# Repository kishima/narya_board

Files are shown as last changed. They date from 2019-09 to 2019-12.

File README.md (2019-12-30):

# Narya board

Narya board is dedicated to [Family mruby](https://github.com/kishima/family_mruby) system.

Latest release is v2.0 and ESP32_WROVER_B_Breakout v1.0.

---

## Narya board v2.0

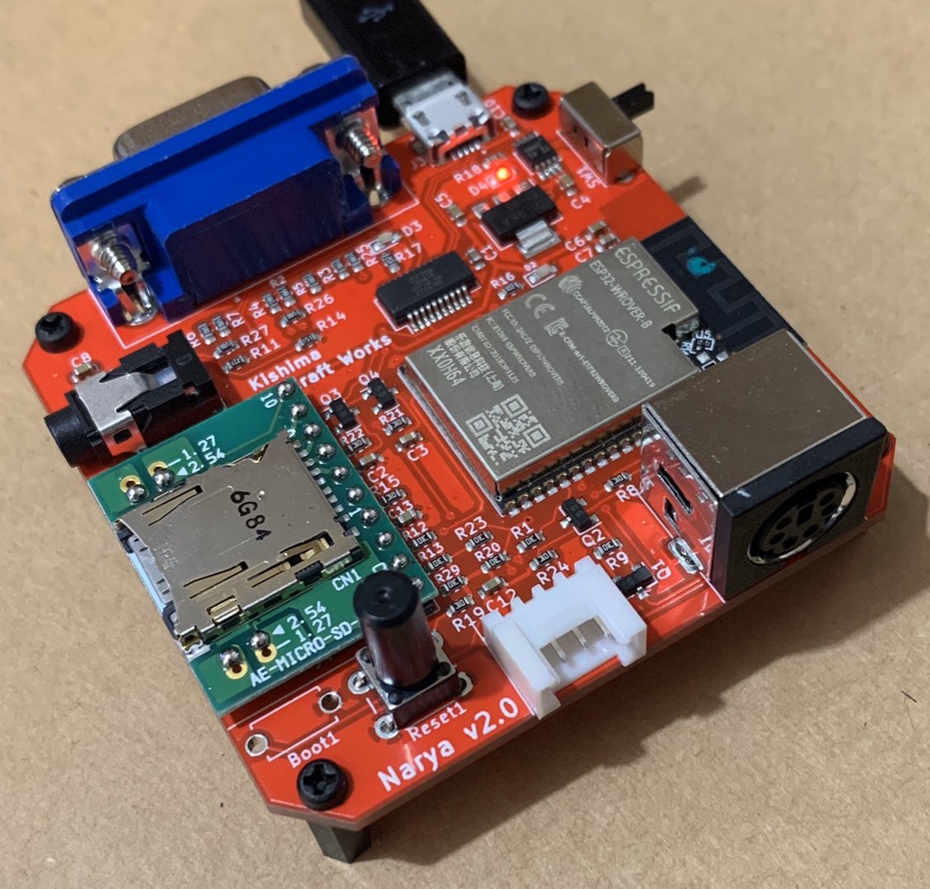
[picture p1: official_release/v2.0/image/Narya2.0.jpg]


CAD data of the case is also released.

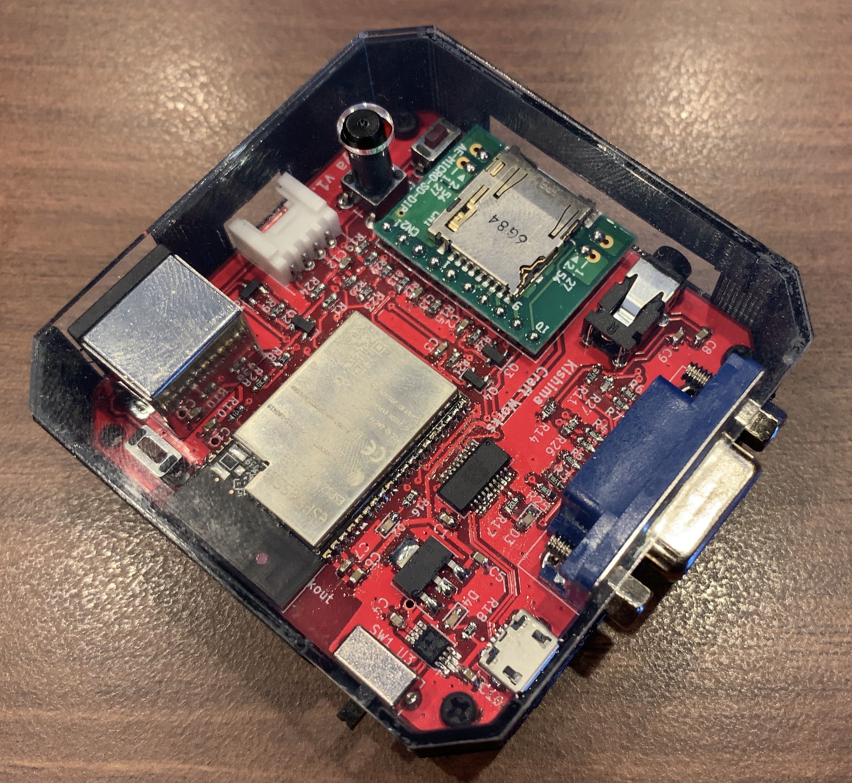
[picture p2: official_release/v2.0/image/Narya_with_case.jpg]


---

## Narya board v1.2

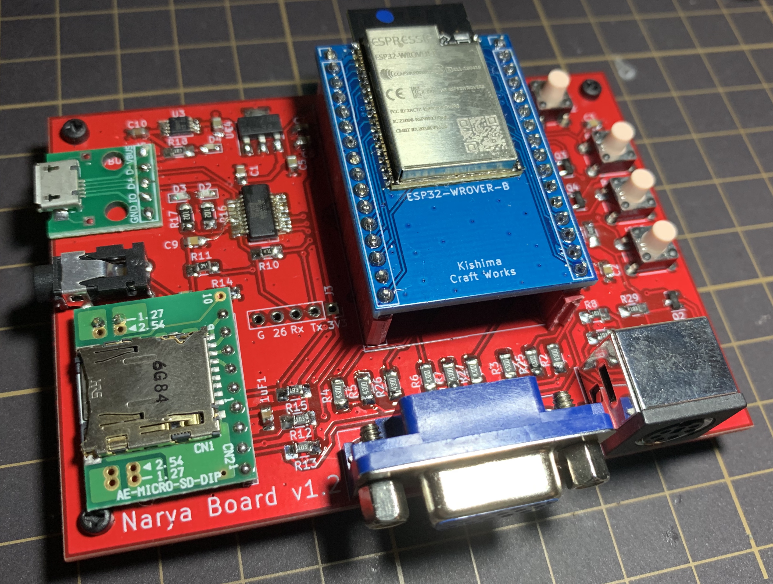
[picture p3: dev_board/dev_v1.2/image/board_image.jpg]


### Known issue

#### Artwork error

The pin16 of "US FT231XS" (GND) is floating in development board v1.2.

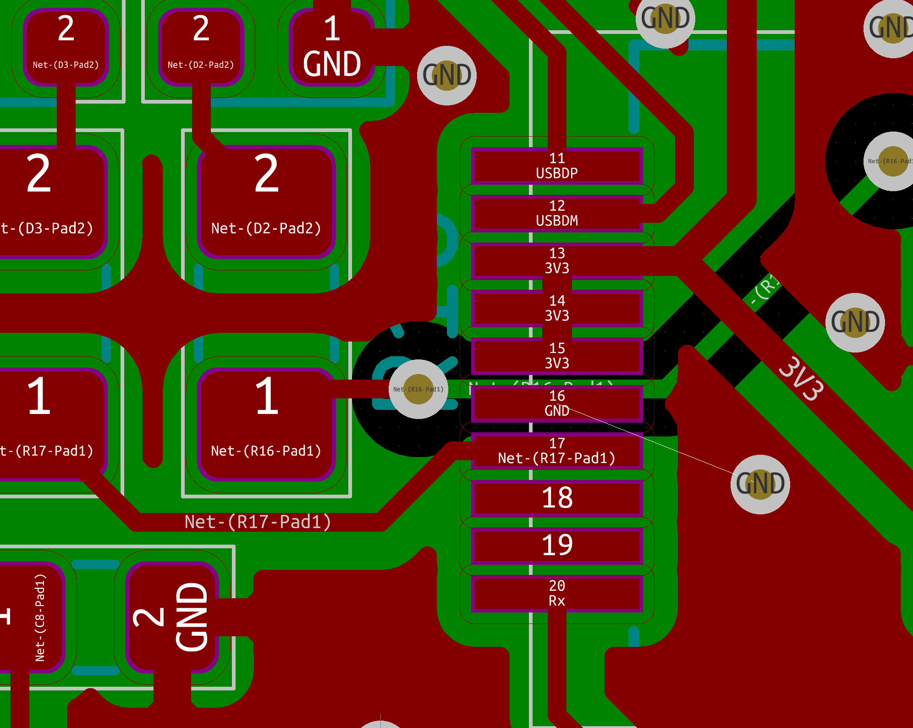
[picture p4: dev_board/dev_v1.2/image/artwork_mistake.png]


---

## History

### v2.0

First version of PCBA production. Released in C97.

Updates

* Fix problem about LED indication.
* Change the power source of the red LED.

### v1.4

Updates

* Update artwork for production.
* Add a GROVE connector
* Add a power swtich

### v1.3

Updates

* Fix issue about FT231X GND.

### v1.2

Released in Tech book fest 7.

### v1.0

First prototype.

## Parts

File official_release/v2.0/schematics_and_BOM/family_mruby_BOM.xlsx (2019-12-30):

# | Reference | Number | Value | Package | Manufacturer Part number | Description | Reference
1 | J6 | 1 | AudioJack2_Ground | myparts:Jack ST-005-G |  | AudioJack2_Ground | http://akizukidenshi.com/catalog/g/gC-02460/
2 | J1 | 1 | Conn_01x04_Male | myparts:GROVE_Connector |  | Conn_01x04_Male | http://akizukidenshi.com/catalog/g/gC-12634/
3 | J2 | 1 | Dsub15_Female | Connector_Dsub:DSUB-15 |  | DB15_Female_HighDensity | https://ja.aliexpress.com/item/32878535872.html?spm=a2g0s.9042311.0.0.7b6c4c4dq2qivm
4 | J4 | 1 | Micro_SD_Card | myparts:AKI-SD-slot |  | Micro_SD_Card | http://akizukidenshi.com/catalog/g/gK-05488/
5 | PS2 | 1 | Mini-DIN-6 | myparts:mini_DIN_6p_useconn |  | Mini-DIN-6 | http://akizukidenshi.com/catalog/g/gC-09385/
6 | C10, C1, C7 | 3 | 0.1uF | Capacitor_SMD:C_0603_1608Metric | CC0603KPX7R7BB104 | C | https://www.digikey.jp/product-detail/ja/yageo/CC0603KPX7R7BB104/311-1335-1-ND/2103119
7 | C3, C9, C2 | 3 | 10nF | Capacitor_SMD:C_0603_1608Metric | CC0603KPX7R9BB103 | C | https://www.digikey.jp/product-detail/ja/CC0603KPX7R9BB103/311-1572-1-ND/4340579/?itemSeq=310468665
8 | C8, C5, C4 | 3 | 10uF | Capacitor_SMD:C_0603_1608Metric | GRM188R61A106KE69J | C | https://www.digikey.jp/product-detail/ja/GRM188R61A106KE69J/490-14372-1-ND/6606833/?itemSeq=310469032
9 | C12, C11, C13 | 3 | 1uF | Capacitor_SMD:C_0603_1608Metric | CC0603KRX5R8BB105 | C | https://www.digikey.jp/product-detail/ja/yageo/CC0603KRX5R8BB105/311-1445-1-ND/2833751
10 | C6 | 1 | 22uF | Capacitor_SMD:C_0603_1608Metric | GRM188R61A226ME15D | C | https://www.digikey.jp/product-detail/ja/murata-electronics/GRM188R61A226ME15D/490-10476-1-ND/5026394
11 | D4 | 1 | LED-R | LED_SMD:LED_0603_1608Metric_Pad1.05x0.95mm_HandSolder | SML-D12U1WT86 | LED | https://www.digikey.jp/product-detail/ja/rohm-semiconductor/SML-D12U1WT86/SML-D12U1WT86CT-ND/5843858
12 | D2, D3 | 2 | LED-G | LED_SMD:LED_0603_1608Metric_Pad1.05x0.95mm_HandSolder | SML-D12M8WT86 | LED | https://www.digikey.jp/product-detail/ja/rohm-semiconductor/SML-D12M8WT86/511-1578-1-ND/1641810
13 | R14 | 1 | 150 Ohm | Resistor_SMD:R_0603_1608Metric | RC0603JR-07150RL | R | https://www.digikey.jp/product-detail/ja/RC0603JR-07150RL/311-150GRCT-ND/729661/?itemSeq=310471572
14 | R23, R15, R18, R1, R24, R19, R13, R29, R28, R8, R9, R20, R12, R21, R22 | 15 | 10K Ohm | Resistor_SMD:R_0603_1608Metric | RC0603FR-0710KL | R | https://www.digikey.jp/product-detail/ja/yageo/RC0603FR-0710KL/311-10.0KHRCT-ND/729827
15 | R17, R16 | 2 | 1K Ohm | Resistor_SMD:R_0603_1608Metric | RC0603JR-071KL | R | https://www.digikey.jp/product-detail/ja/yageo/RC0603JR-071KL/311-1.0KGRCT-ND/729624
16 | R11 | 1 | 270 Ohm | Resistor_SMD:R_0603_1608Metric | RC0603FR-07270RL | R | https://www.digikey.jp/product-detail/ja/yageo/RC0603FR-07270RL/311-270HRCT-ND/730050
17 | R6, R3, R2, R7, R5, R26, R4, R27, R25 | 9 | 402 Ohm | Resistor_SMD:R_0603_1608Metric | RC0603FR-07402RL | R | https://www.digikey.jp/product-detail/ja/yageo/RC0603FR-07402RL/311-402HRCT-ND/730169
18 | R10 | 1 | 470 Ohm | Resistor_SMD:R_0603_1608Metric | RC0603FR-07470RL | R | https://www.digikey.jp/product-detail/ja/yageo/RC0603FR-07470RL/311-470HRCT-ND/730203
19 | U1 | 1 | FT231XS | Package_SO:SSOP-20_3.9x8.7mm_P0.635mm | FT231XS-R | FT231XS | https://www.digikey.jp/product-detail/ja/ftdi-future-technology-devices-international-ltd/FT231XS-R/768-1129-1-ND/3029151
20 | U4 | 1 | AP7361C-33E | Package_TO_SOT_SMD:SOT-223-3_TabPin2 | AP7361C-33E-13 | AP7361C-33E | https://www.digikey.jp/product-detail/ja/AP7361C-33E-13/AP7361C-33E-13DICT-ND/5638331/?itemSeq=310400924
21 | Reset1 | 1 | SW_Push | Button_Switch_THT:SW_PUSH_6mm |  | SW_Push | http://akizukidenshi.com/catalog/g/gP-09824/
22 | IO35, Boot1 | 2 | SW_Push | myparts:TVBP06-BN043CR-B |  | SW_Push | http://akizukidenshi.com/catalog/g/gP-08213/
23 | SW1 | 1 | SW_Push_SPDT | myparts:SK-12D01-VG4 |  | SW_Push_SPDT | http://akizukidenshi.com/catalog/g/gP-08789/
24 | Q1, Q2, Q4, Q3 | 4 | BSS138 | Package_TO_SOT_SMD:SOT-23 | BSS138 | BSS138 | https://www.digikey.jp/product-detail/ja/BSS138/BSS138CT-ND/244294/?itemSeq=310461796
25 | J3 | 1 | 10118194-0001LF | 10118194-0001LF | 10118194-0001LF | 10118194-0001LF | https://www.digikey.jp/product-detail/ja/10118194-0001LF/609-4618-1-ND/2785382/?itemSeq=310466331
26 | UB1 | 1 | ESP32-WROVER-B | ESP32-WROVER-B_(16MB) | ESP32-WROVER-B (M213DH6464PC3Q0) | ESP32-WROVER-B | https://www.digikey.jp/product-detail/ja/ESP32-WROVER-B+(M213DH6464PC3Q0)/1904-1034-1-ND/9857845/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
19 | U3 | 1 | TPS2065DGNR | MSOP-8_3x3mm_P0.65mm | TPS2065DGNR | TPS2065 | https://www.digikey.jp/product-detail/ja/TPS2065DGNR/296-17314-1-ND/684819/?itemSeq=310404582

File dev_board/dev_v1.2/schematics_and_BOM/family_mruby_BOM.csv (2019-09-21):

Library | Part | Footprint | Value | Number | Reference | 調達先（例）
Connector | AudioJack2_Ground | myparts:Jack ST-005-G | AudioJack2_Ground | 1 | J6 | http://akizukidenshi.com/catalog/g/gC-02460/
Connector | Conn_01x05_Female | Connector_PinHeader_2.54mm:PinHeader_1x05_P2.54mm_Vertical | MicroUSB_DIP | 1 | J5 | https://www.amazon.co.jp/dp/B0183KF7TM/ref=cm_sw_em_r_mt_dp_U_rBJHDbKRYNB0A
Connector | Conn_01x05_Female | Connector_PinSocket_2.54mm:PinSocket_1x05_P2.54mm_Vertical | Pin_UARAT_IO26 | 1 | J3 | -
Connector | DB15_Female_HighDensity | Connector_Dsub:DSUB-15-HD_Female_Horizontal_P2.29x1.98mm_EdgePinOffset3.03mm_Housed_MountingHolesOffset4.94mm | Dsub15_Female | 1 | J2 | https://ja.aliexpress.com/item/32878535872.html?spm=a2g0s.9042311.0.0.4e0d4c4dXb4pk2
Connector | Micro_SD_Card | Connector_PinHeader_2.54mm:PinHeader_1x09_P2.54mm_Vertical | Micro_SD_Card | 1 | J4 | http://akizukidenshi.com/catalog/g/gK-05488/
Connector | Mini-DIN-6 | myparts:mini_DIN_6p_useconn | Mini-DIN-6 | 1 | PS2 | http://akizukidenshi.com/catalog/g/gC-09385/
Device | C | Capacitor_SMD:C_0805_2012Metric_Pad1.15x1.40mm_HandSolder | 0.1uF | 2 | C7, C1 | 千石電商等で
Device | C | Capacitor_SMD:C_0805_2012Metric_Pad1.15x1.40mm_HandSolder | 100nF | 1 | C10 | 千石電商等で
Device | C | Capacitor_SMD:C_0805_2012Metric_Pad1.15x1.40mm_HandSolder | 10nF | 3 | C2, C3, C9 | 千石電商等で
Device | C | Capacitor_SMD:C_0805_2012Metric_Pad1.15x1.40mm_HandSolder | 10uF | 3 | C8, C5, C4 | 千石電商等で
Device | C | Capacitor_SMD:C_0805_2012Metric_Pad1.15x1.40mm_HandSolder | 1uF | 1 | 1uF1 | 千石電商等で
Device | C | Capacitor_SMD:C_0805_2012Metric_Pad1.15x1.40mm_HandSolder | 22uF | 1 | C6 | 千石電商等で
Device | LED | LED_SMD:LED_0603_1608Metric_Pad1.05x0.95mm_HandSolder | LED | 3 | D2, D3, D4 | http://akizukidenshi.com/catalog/g/gI-03978/
Device | R | Resistor_SMD:R_1206_3216Metric_Pad1.42x1.75mm_HandSolder | 100 | 1 | R14 | 千石電商等で
Device | R | Resistor_SMD:R_1206_3216Metric_Pad1.42x1.75mm_HandSolder | 10K | 15 | R29, R22, R20, R13, R15, R18, R12, R23, R24, R28, R8, R21, R1, R19, R9 | 千石電商等で
Device | R | Resistor_SMD:R_1206_3216Metric_Pad1.42x1.75mm_HandSolder | 1K | 2 | R17, R16 | 千石電商等で
Device | R | Resistor_SMD:R_1206_3216Metric_Pad1.42x1.75mm_HandSolder | 240 | 1 | R11 | 千石電商等で
Device | R | Resistor_SMD:R_1206_3216Metric_Pad1.42x1.75mm_HandSolder | 420 | 9 | R3, R5, R4, R6, R25, R26, R27, R2, R7 | 千石電商等で
Device | R | Resistor_SMD:R_1206_3216Metric_Pad1.42x1.75mm_HandSolder | 470 | 1 | R10 | 千石電商等で
Interface_USB | FT231XS | Package_SO:SSOP-20_3.9x8.7mm_P0.635mm_handsolder | FT231XS | 1 | U2 | http://akizukidenshi.com/catalog/g/gI-06713/
Regulator_Linear | AP7361C-33E | Package_TO_SOT_SMD:SOT-223-3_TabPin2 | AP7361C-33E | 1 | U4 | DigiKey等で
Switch | SW_Push | Button_Switch_THT:SW_PUSH_6mm | SW_Push | 4 | IO35, IO34, Boot1, Reset1 | http://akizukidenshi.com/catalog/g/gP-03649/
Transistor_FET | BSS138 | Package_TO_SOT_SMD:SOT-23 | BSS138 | 4 | Q3, Q1, Q4, Q2 | http://akizukidenshi.com/catalog/g/gI-04232/
mysymbol | ESP32-WROVER-B_breakout | myparts:ESP32-WROVER-B_breakout | ESP32-WROVER-B_breakout | 1 | UB1 | -
mysymbol | TPS2065 | myparts:TPS2065_MSOP-8_3x3mm_P0.65mm | TPS2065 | 1 | U3 | DigiKey等で

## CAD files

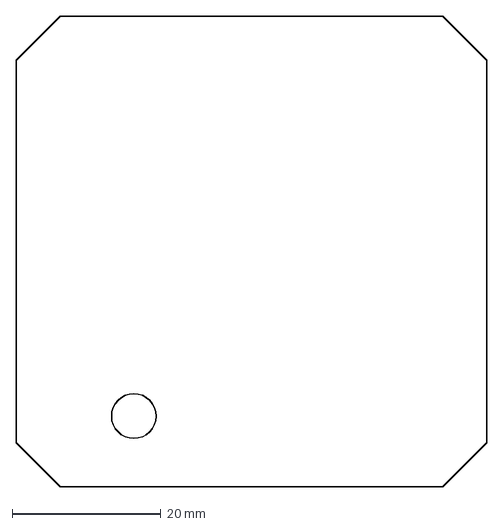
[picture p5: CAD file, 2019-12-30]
official_release/v2.0/case/Narya_v2.0_top_plate.dxf
63.2 x 63.2 mm

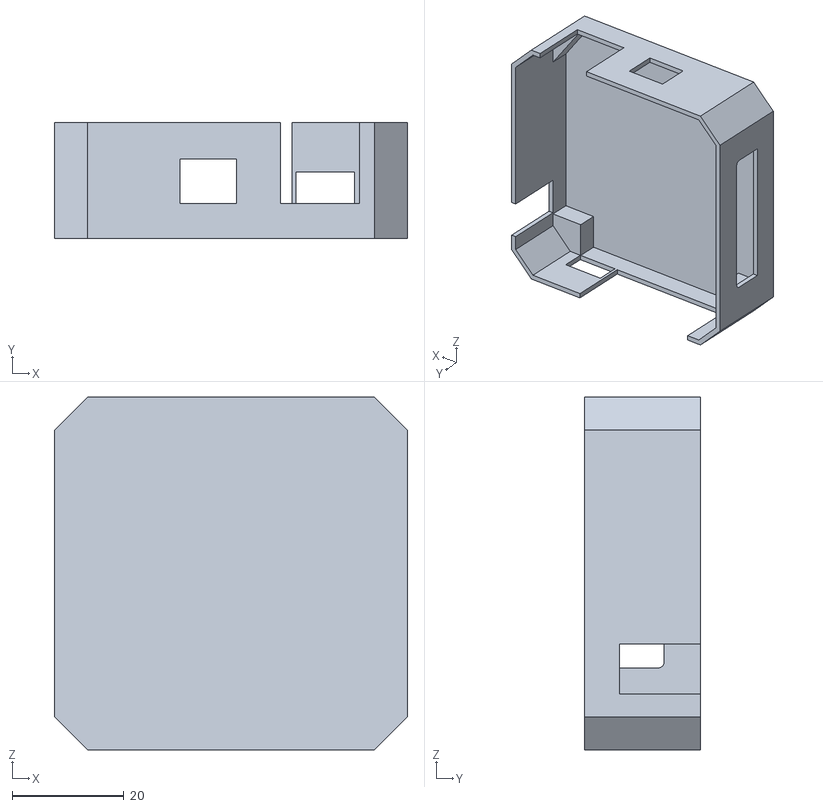
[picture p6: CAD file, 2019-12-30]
official_release/v2.0/case/Narya_v2,0_caseB.stl
63.2 x 20.7 x 63.2

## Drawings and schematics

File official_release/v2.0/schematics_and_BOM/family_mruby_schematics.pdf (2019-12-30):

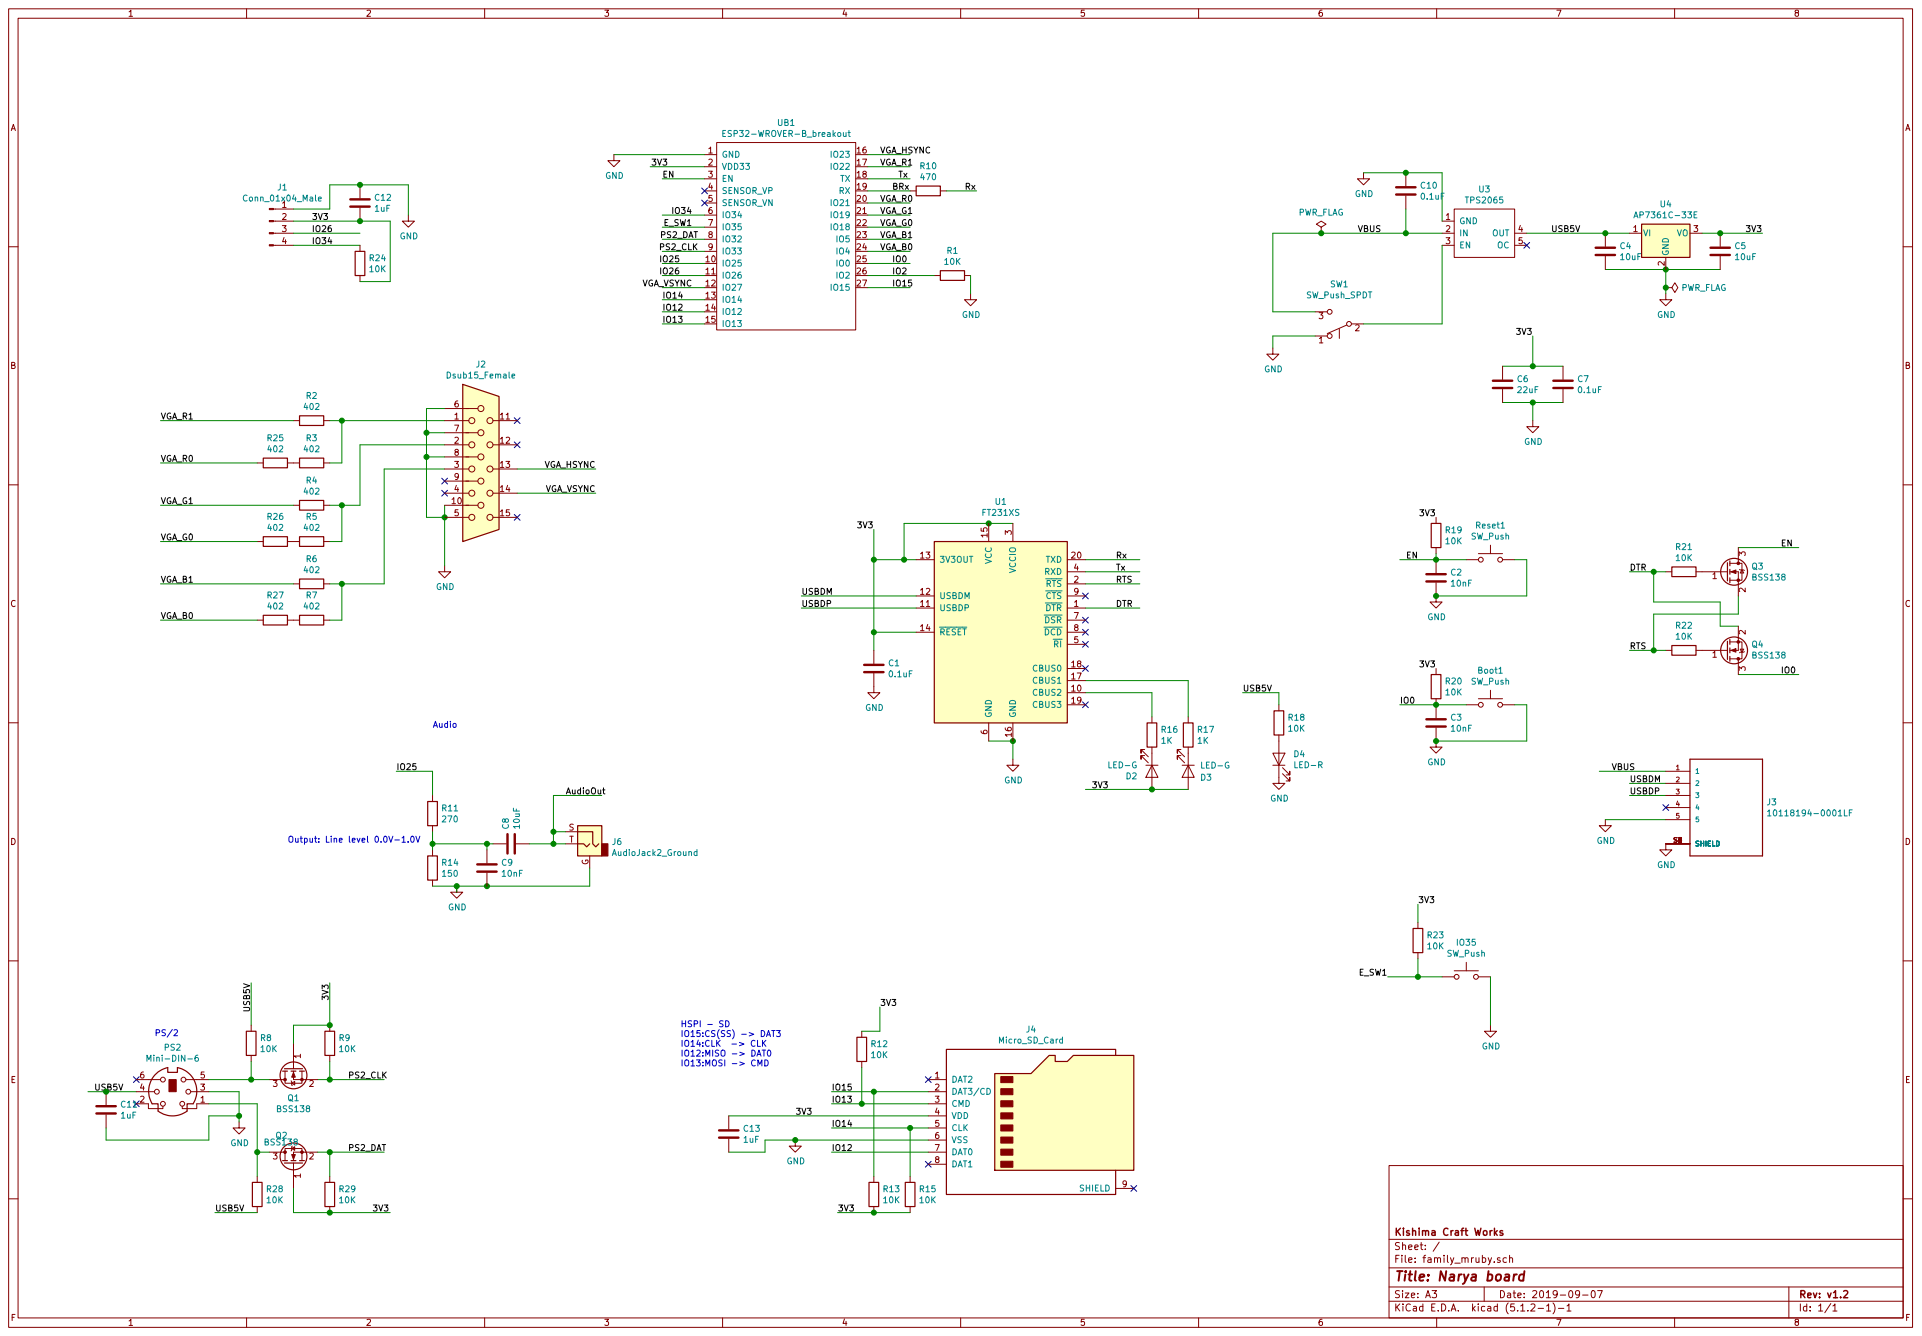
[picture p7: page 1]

File: family_mruby.sch Sheet: / Kishima Craft Works

Id: 1/1 Title: Narya board

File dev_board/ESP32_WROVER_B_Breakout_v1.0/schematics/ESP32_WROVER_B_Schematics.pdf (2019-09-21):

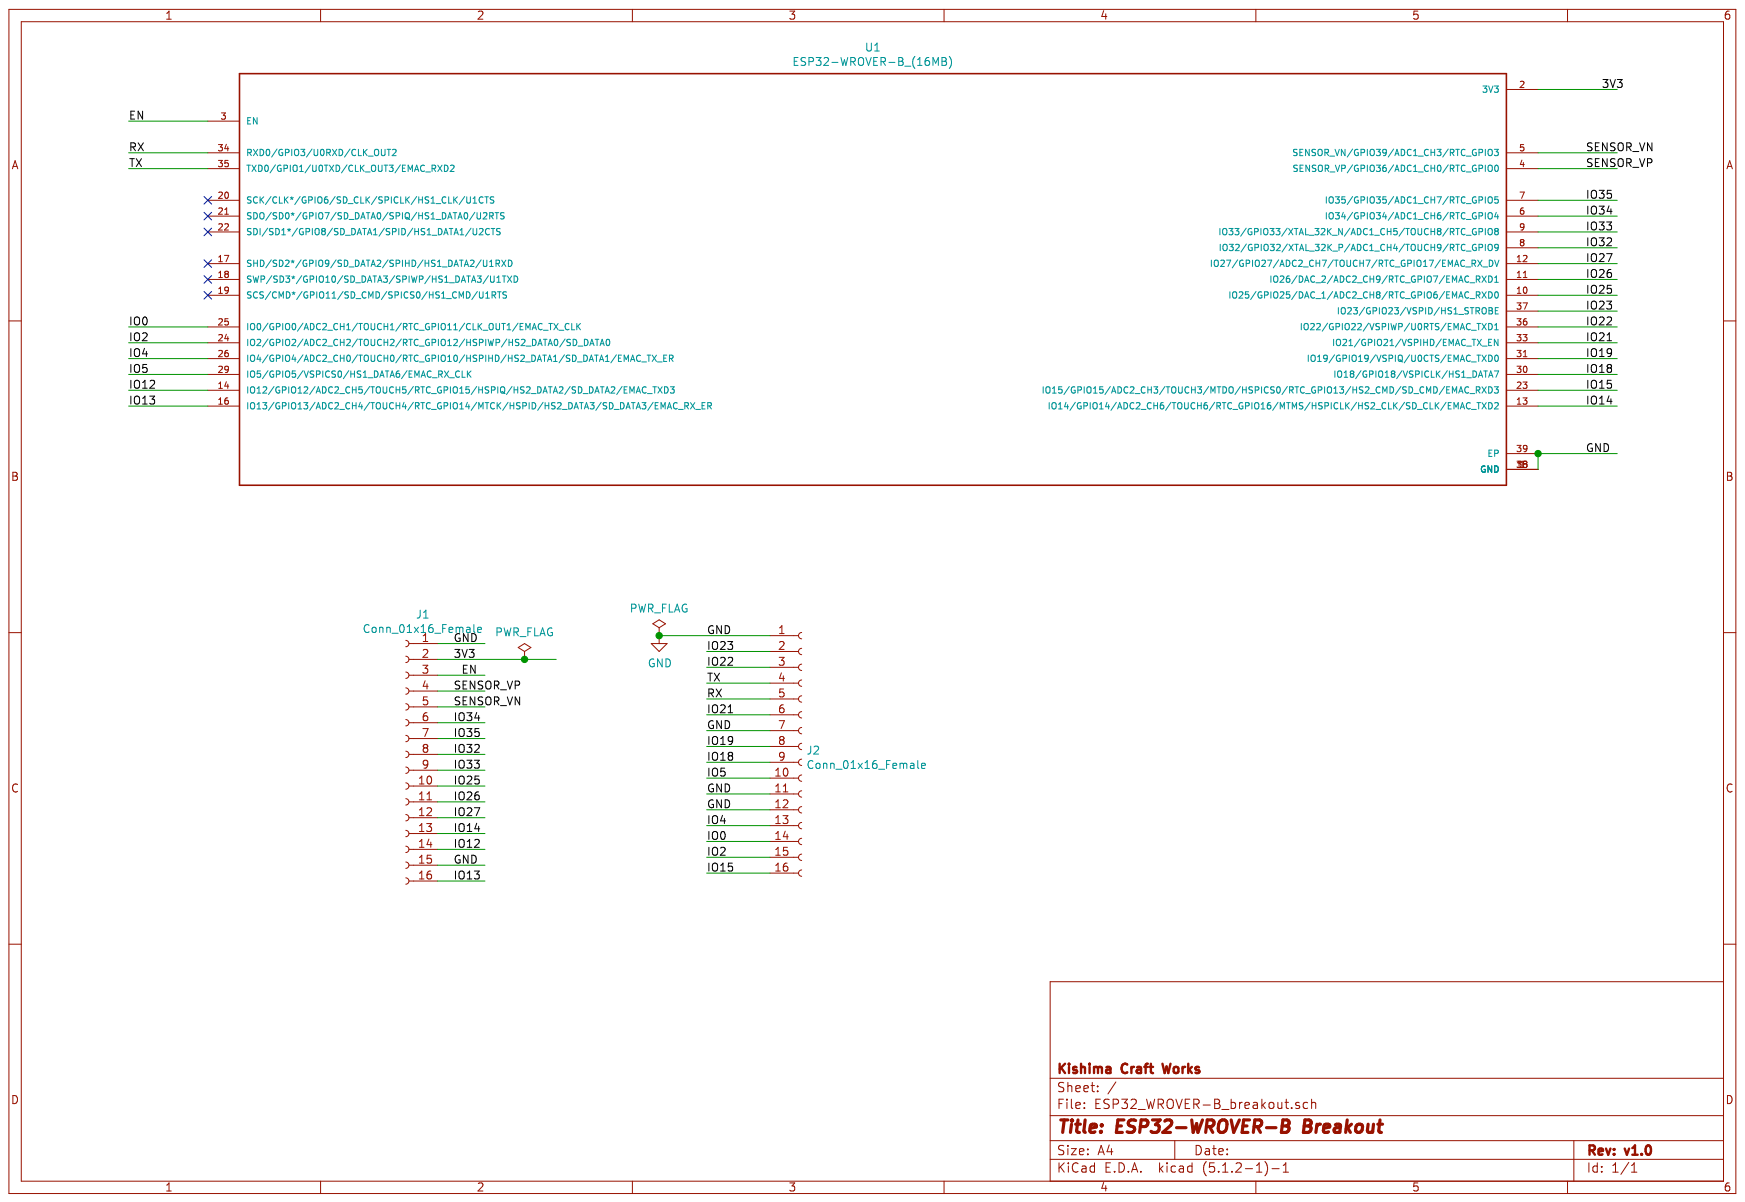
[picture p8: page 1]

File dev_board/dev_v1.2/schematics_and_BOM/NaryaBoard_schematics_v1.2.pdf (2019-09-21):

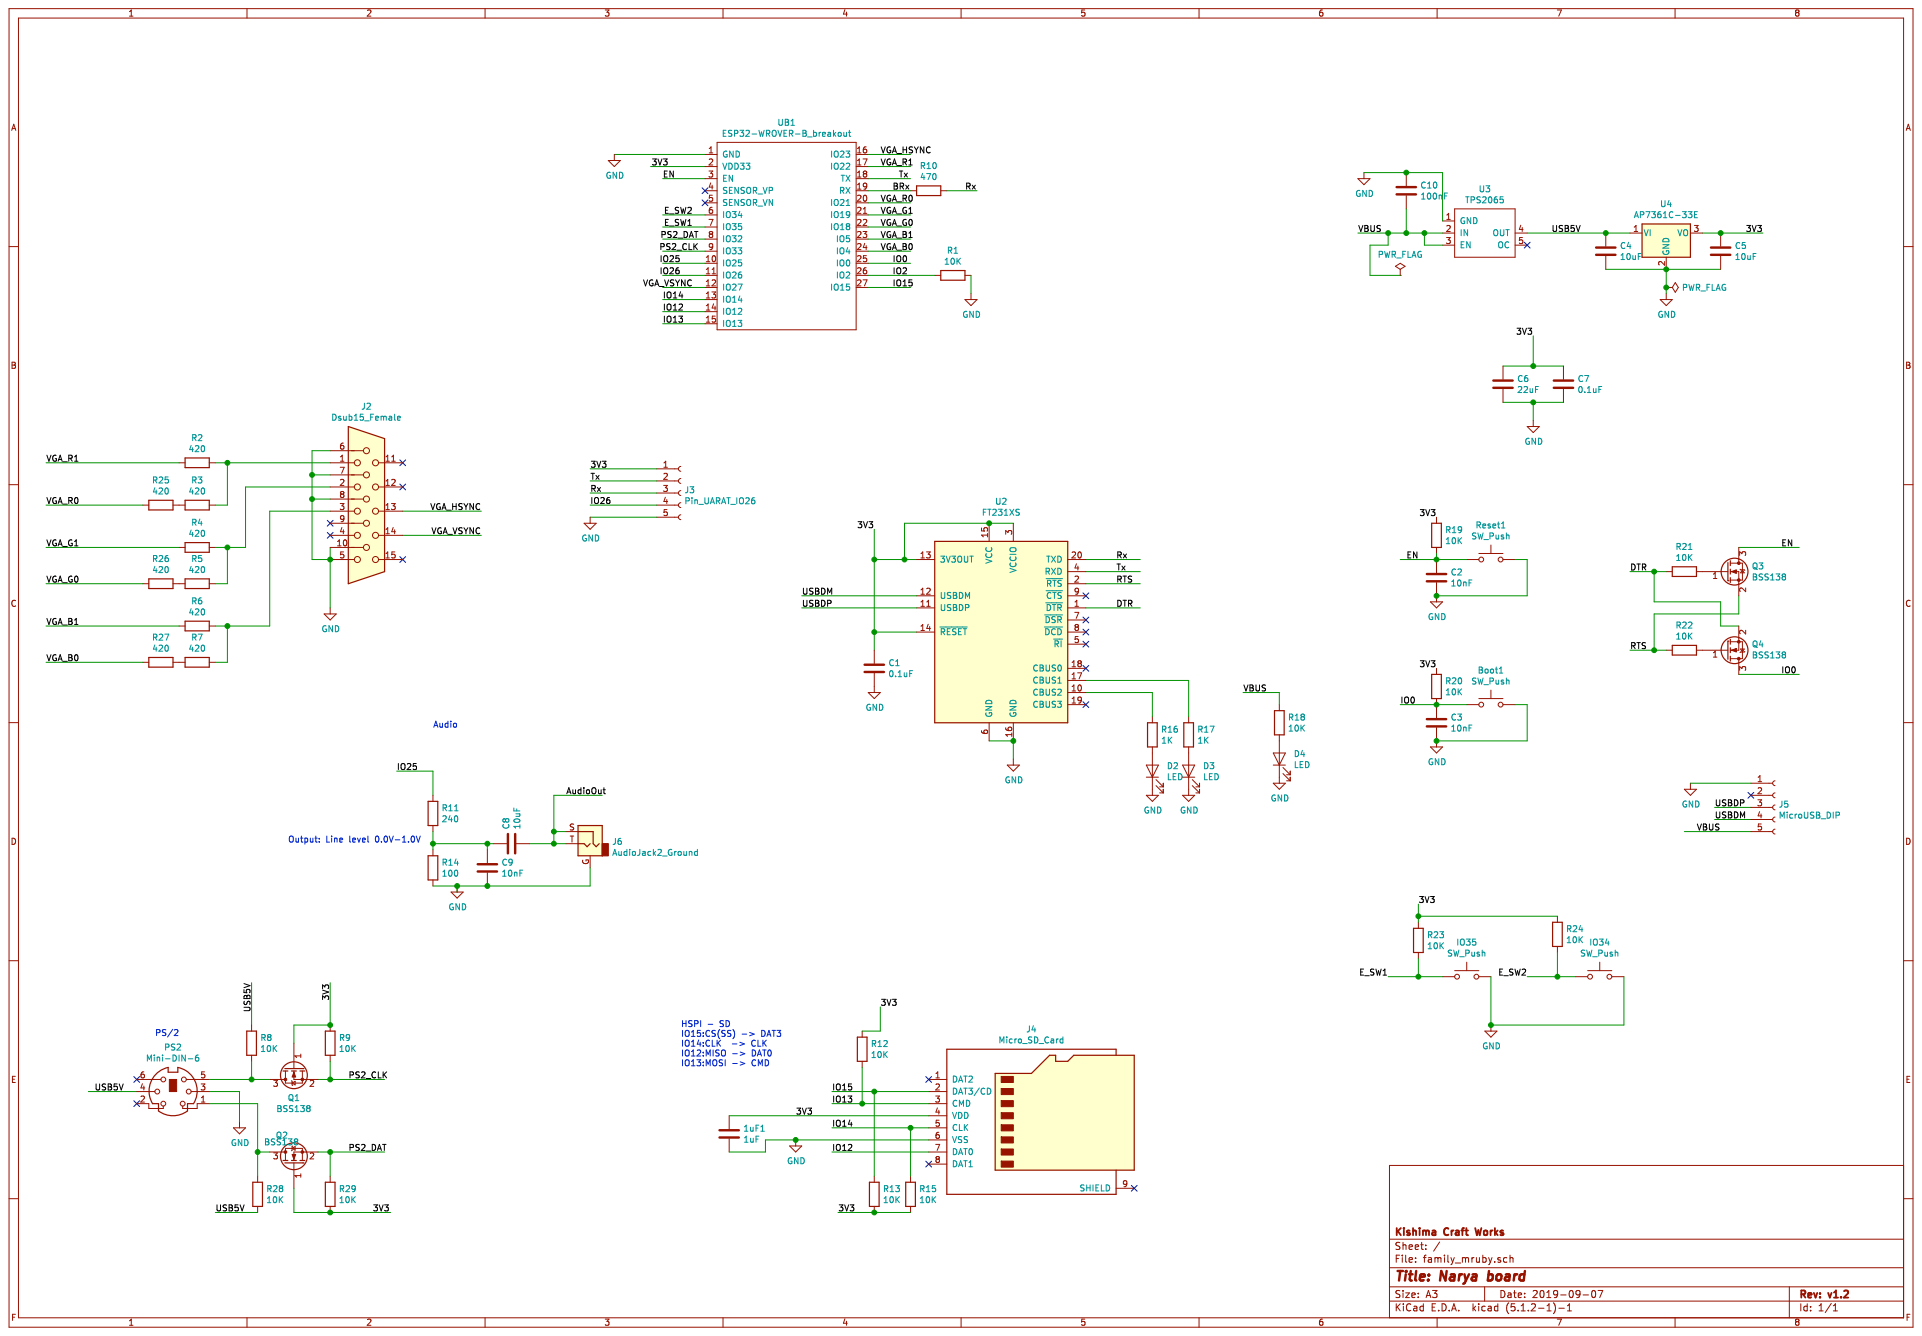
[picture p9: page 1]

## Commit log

2019-09-21 add board info of dev-v1.2
    [family_mruby_BOM.csv]
2019-09-21 add breakout board info
2019-09-21 add kicad data
2019-12-30 add v2.0 data
    [family_mruby_BOM.xlsx]
2019-12-30 add case CAD data
    [Narya_v2,0_caseB.stl, Narya_v2.0_top_plate.dxf]
